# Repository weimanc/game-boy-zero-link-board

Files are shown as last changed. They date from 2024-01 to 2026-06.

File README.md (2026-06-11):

# Game-Boy-Zero-Link-Board

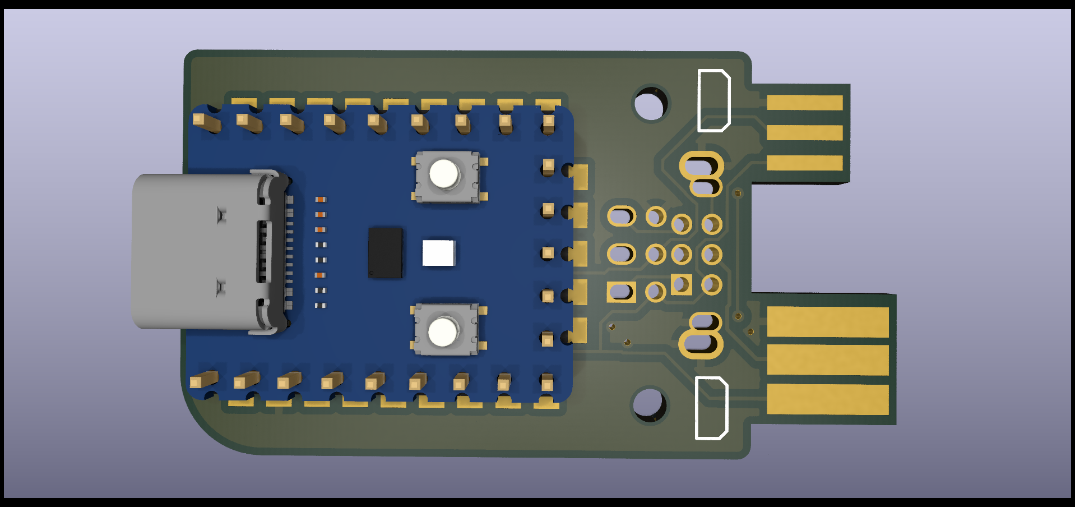
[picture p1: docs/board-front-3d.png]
Board 3D Render


This project is forked from agtbaskara. This is the first time I'm using KiCad and Github. The experience is very pleasant to build on top of other people's work. Even this README.md is forked and extended ;). Check out the [References](#References).

Like agtbaskara, this is another Open-Source USB to Gameboy Link Cable Adapter based around the smaller and cheaper RP2040-Zero. Designed with components that are easy to source and solder.

Game-Boy-Zero-Link-Board offers multiple options to connect your GB link cable.
- J1 GBA/GBC PCB Edge connector
- J2 DMG PCB Edge connector
- J3 DMG/GBA/GBC/IDC combined footprint

Game-Boy-Zero-Link-Board uses GBVCC (PIN1 of the GB link cable) to power the HV side of the Logic Level Converter. This allows the board to autmatically resolve the correct voltage on the GB side.

Based on stacksmashing Gameboy Link adapter: https://www.youtube.com/watch?v=KtHu693wE9o

# Schematic

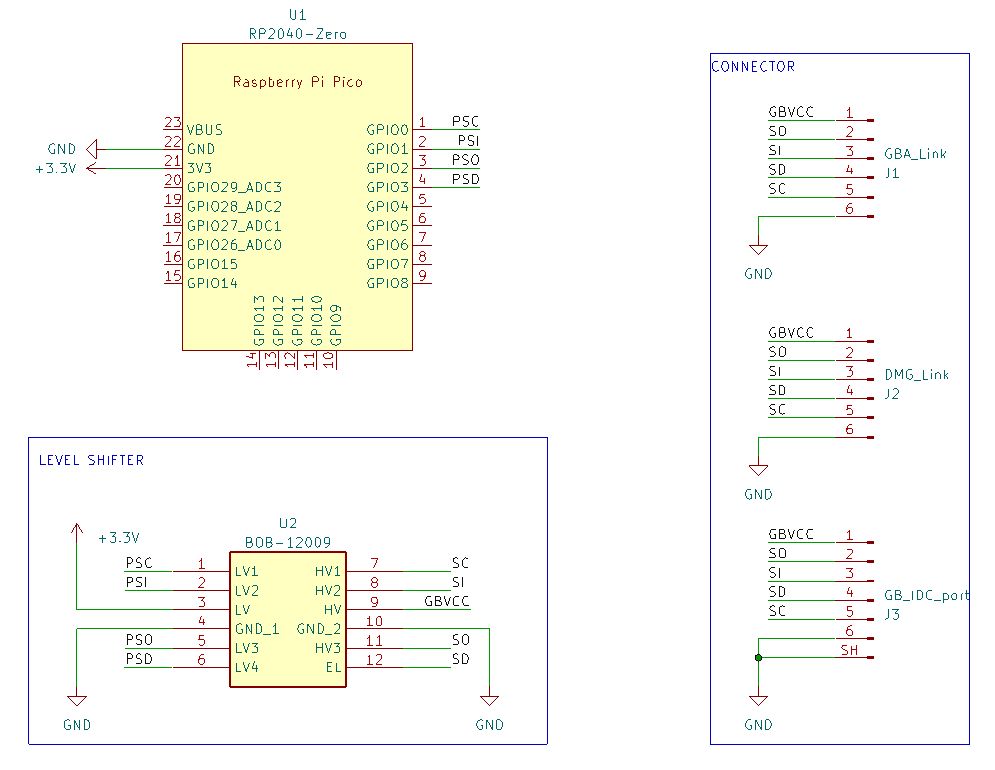
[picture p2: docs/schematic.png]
Schematic


# Required Components

| Reference | Part Number | Description |
|-|-|-|
| U1 | [RP2040-Zero](https://www.waveshare.com/wiki/RP2040-Zero) | Waveshare RP2040-Zero |
| U1* | [RP2040-Zero](https://www.aliexpress.com/item/1005005994987953.html) | AliExpress RP2040-Zero |
| U2 | [BOB-12009](https://www.sparkfun.com/products/12009) | Sparkfun Bi-Directional Logic Level Converter, clones are compatible |
| U2* | [BOB-12009](https://www.aliexpress.com/item/1005006068381598.html) |  AliExpress Bi-Directional Logic Level Converter|
| J1/J2 | [DMG-GBC-cable](https://www.aliexpress.com/item/1005004110251579.html) | AliExpress link cable suitable for DMG and GBC|
| J3 | [GBA_link](https://www.aliexpress.com/item/1005006181192248.html) | AliExpress GBA link port |

**Attached links are for reference only, you can use any equivalent parts.**

# How to Order Board

To order a board, use the `gerbers*.zip` from the release page or generate one yourself. You can order from your favourite PCB manufacturer ([JLCPCB](https://jlcpcb.com/), [PCBWay](https://www.pcbway.com/), etc.).

**Use 1.2mm PCB thickness.**

You can choose any colour for the Solder Mask and Silkscreen. For the Surface Finish, ENIG is recommended.

# How to Assemble Board

1. Solder pin header to RP2040-Zero and Level Shifter module. Use a breadboard for easier soldering
2. Solder RP2040-Zero and Level Shifter module to the board
3. Cut the excessive pin using a nipper tool
4. Flash firmware to your RP2040-Zero (see [Compatibility](#Compatibility))

# How to Use Board

Connect the board to your PC, and connect the board to your Gameboy using a Link Cable.

# Compatibility

This board is compatible with the following firmware:
- https://github.com/stacksmashing/gb-link-firmware
- https://github.com/stacksmashing/gb-link-printer
- https://github.com/Lorenzooone/PokemonGB_Online_Trades
- https://github.com/dj505/GBPrinterEmu
- https://github.com/Squaresweets/GBPrinter-discord-bot
- https://github.com/KuestenKeks/pc-to-gb-printer
- https://github.com/PaulMDemers/poke-link

With some modification, it should be compatible with other firmware as well, such as:
- https://github.com/untoxa/pico-gb-printer

# References
- Game-Boy-Pico-Link-Board: https://github.com/agtbaskara/game-boy-pico-link-board
- Waveshare RP2040-Zero Footprint: https://files.waveshare.com/upload/f/f7/RP2040_Zero_stp.zip
- Logic Level Converter (BOB-12009) Footprint: https://www.snapeda.com/parts/BOB-12009/SparkFun%20Electronics/view-part/
- Gameboy Link Connector Footprint: https://github.com/Palmr/gb-link-cable
- Gameboy Link Port Footprint: https://github.com/Gekkio/gb-hardware
- 1.2mm PCB Thickness, based on: https://hackaday.io/project/12932-game-link-online/log/43999-received-the-breakout-boards
- Print your own DMG link cable plug: https://www.thingiverse.com/thing:4685189

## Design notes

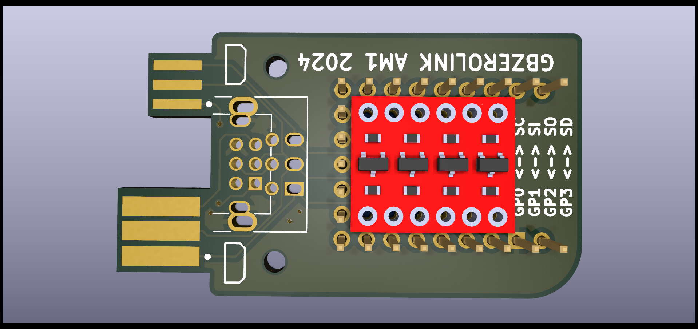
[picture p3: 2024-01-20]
docs/board-back-3d.png

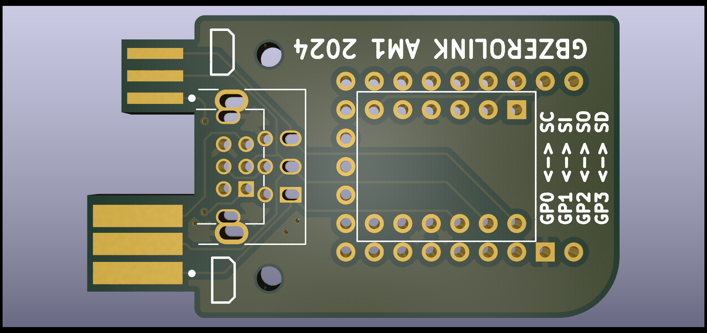
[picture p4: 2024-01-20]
docs/board-back-3d-bare.png

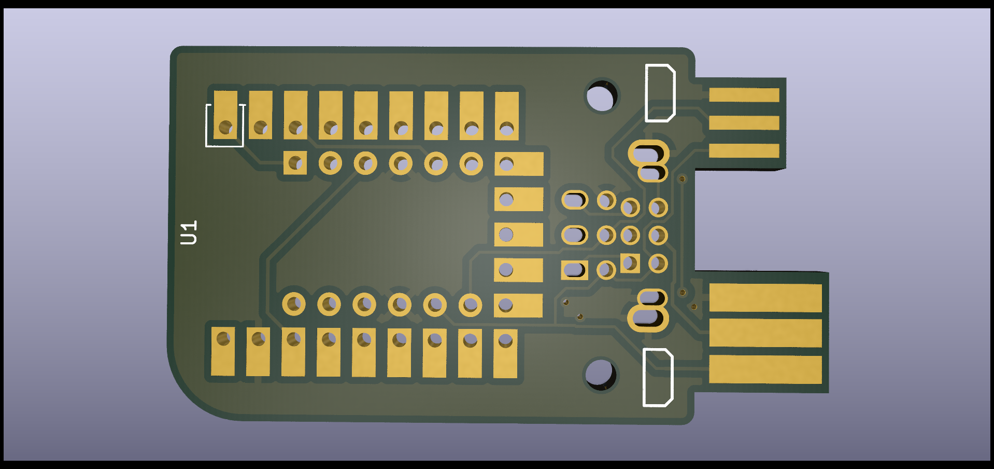
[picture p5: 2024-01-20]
docs/board-front-3d-bare.png

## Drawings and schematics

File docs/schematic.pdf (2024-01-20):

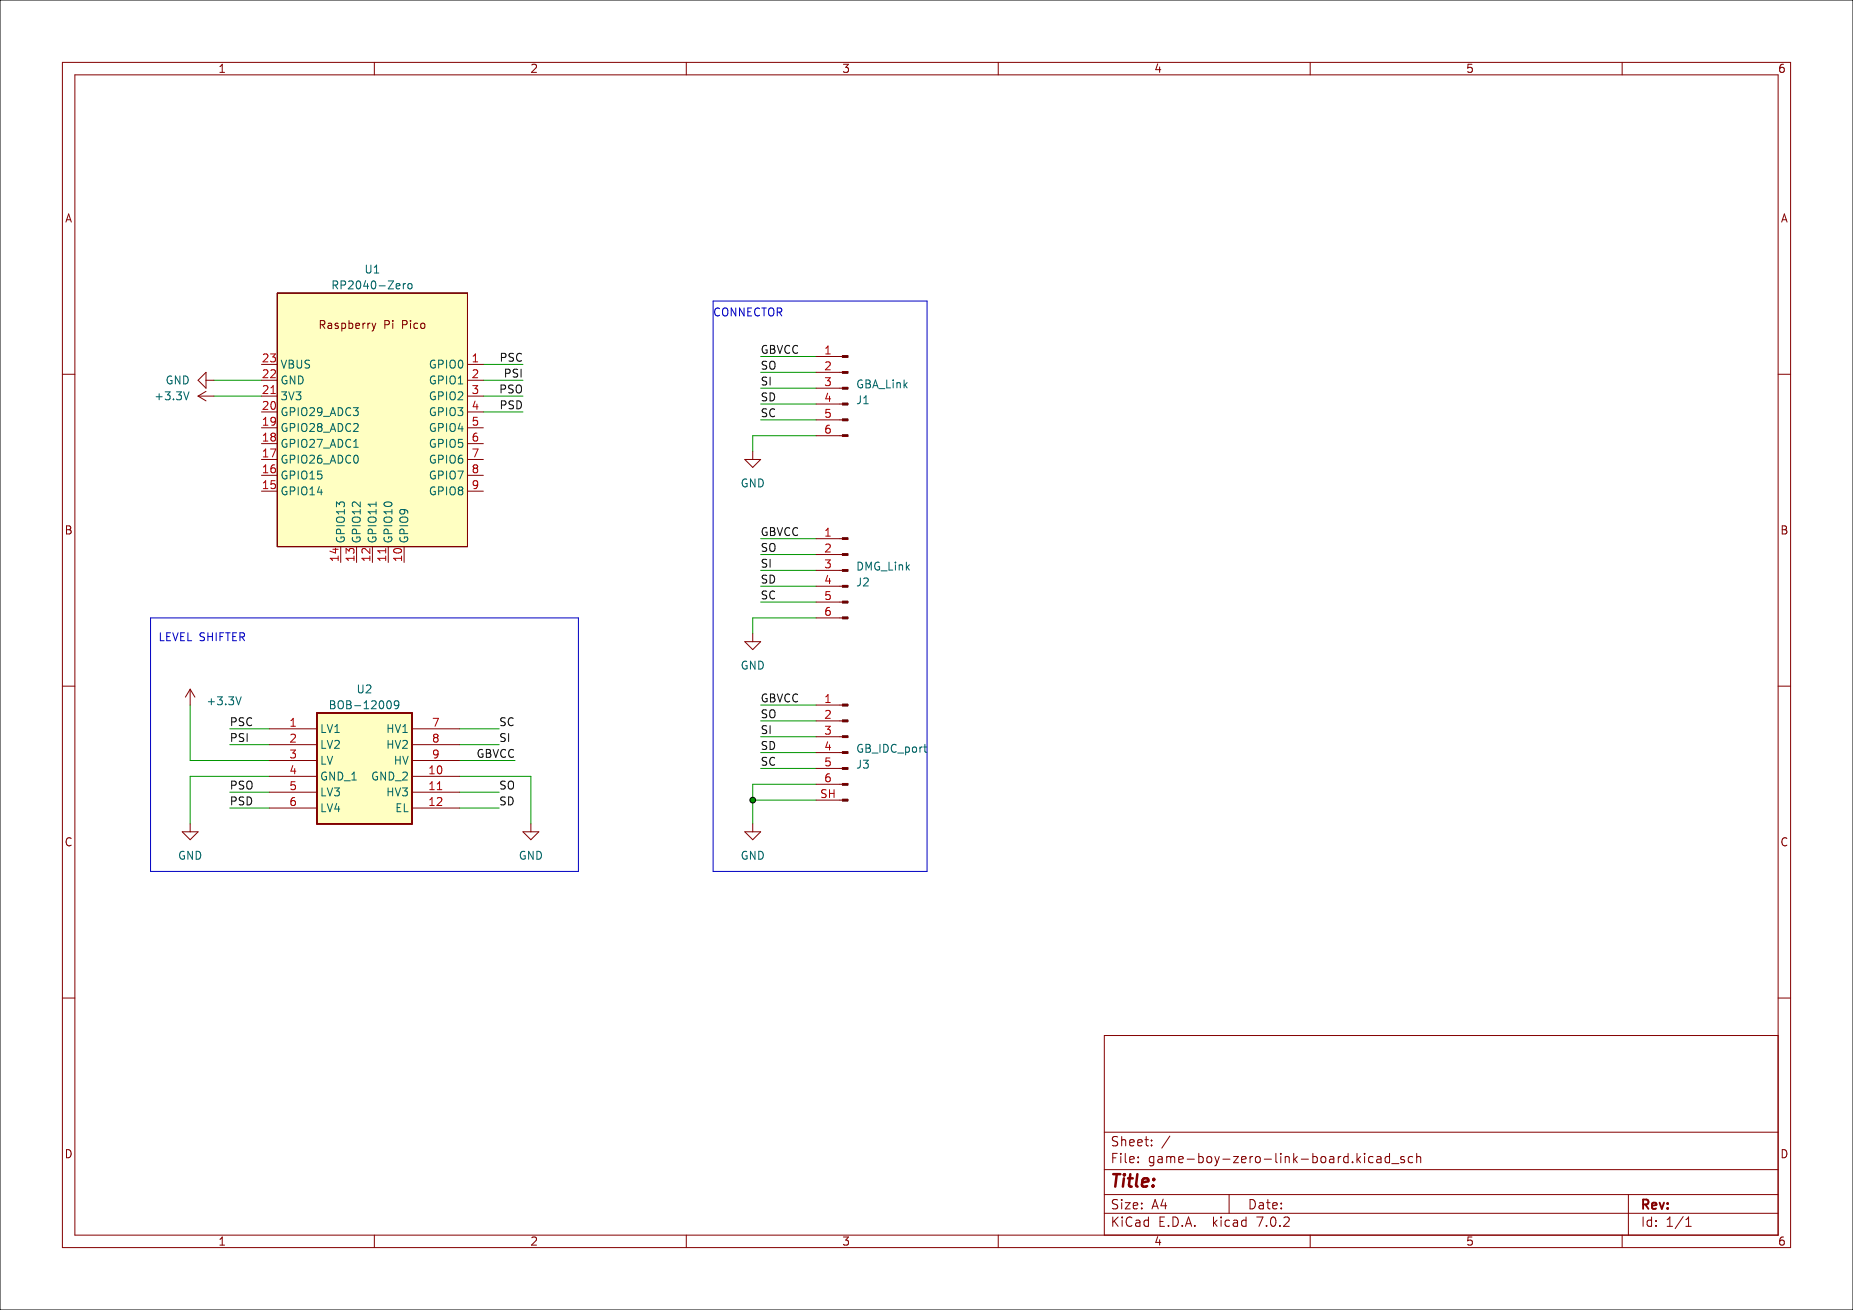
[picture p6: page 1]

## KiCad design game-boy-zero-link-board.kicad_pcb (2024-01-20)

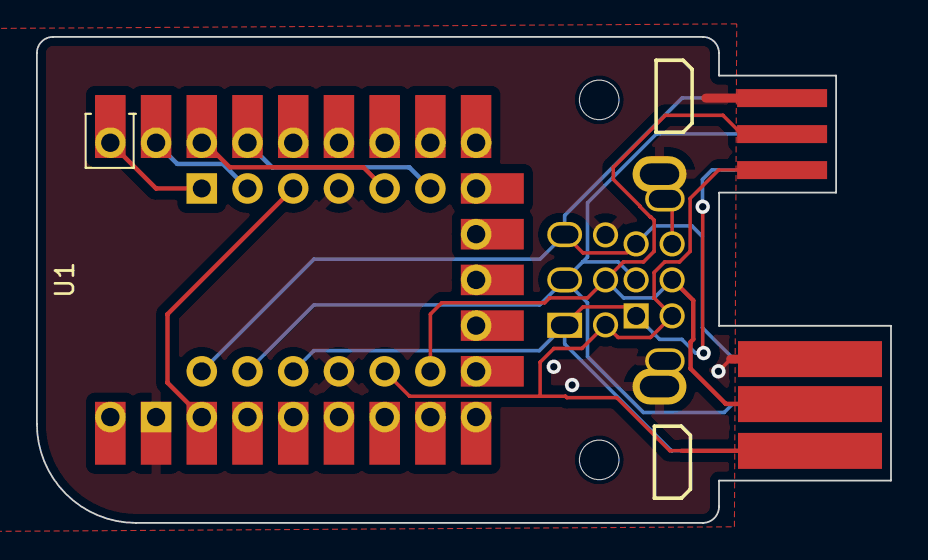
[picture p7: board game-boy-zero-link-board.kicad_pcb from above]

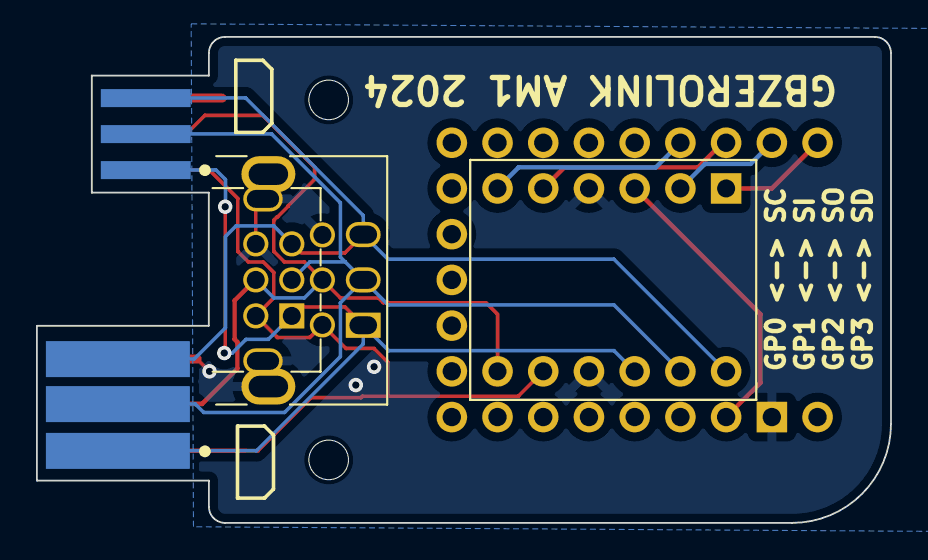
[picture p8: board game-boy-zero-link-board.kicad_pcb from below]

Board: 2 copper layers, 47.5 x 27.0 mm, 5 parts (2 on the bottom side), 11 nets.

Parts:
J1: GBA_Link; gb-link-socket
J2: DMG_Link; dmg-link-socket
J3: GB_IDC_port; GameBoy_LinkPort_DMG_MGB_IDC_Horizontal
U1: RP2040-Zero; RP2040-Zero_SMD_TH
Ue: BOB-12009

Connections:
+3.3V: U1.21 (3V3), Ue.3 (LV)
/GBVCC: J1.1, J2.1, J3.1, Ue.9 (HV)
/PSC: U1.1 (GPIO0), Ue.1 (LV1)
/PSD: U1.4 (GPIO3), Ue.6 (LV4)
/PSI: U1.2 (GPIO1), Ue.2 (LV2)
/PSO: U1.3 (GPIO2), Ue.5 (LV3)
/SC: J1.5, J2.5, J3.5, Ue.7 (HV1)
/SD: J1.4, J2.4, J3.4, Ue.12 (EL)
/SI: J1.3, J2.3, J3.3, Ue.8 (HV2)
/SO: J1.2, J2.2, J3.2, Ue.11 (HV3)
GND: J1.6, J2.6, J3.6, J3.SH, U1.22 (GND), Ue.4 (GND_1), Ue.10 (GND_2)

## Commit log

2024-01-20 Rename and prep project -Rename files to reflect new project name: game-boy-pico-link-board -remove gerbers/paste files -remove lck file -add *.lck in git ignore
    [game-boy-pico-link-board-B_Paste.gbp, game-boy-pico-link-board-F_Paste.gtp, game-boy-zero-link-board-B_Cu.gbl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]
2024-01-20 commit local changes (untested)
    [game-boy-zero-link-board-B_Cu.gbl, game-boy-zero-link-board-B_Mask.gbs, game-boy-zero-link-board-B_Silkscreen.gbo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]
2024-01-20 Made some correction in the README.md add schematic.pdf, board-back-3d-bare.png adjust PCB thickness to 1.2mm and export game-boy-zero-link-board.wrl add missing library files
    [game-boy-zero-link-board.kicad_pcb]
